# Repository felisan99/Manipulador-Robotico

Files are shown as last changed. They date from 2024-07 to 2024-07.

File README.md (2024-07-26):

# Manipulado Robótico

Este proyecto consiste en un brazo robótico a pequeña escala controlado mediante gestos de la mano. A continuación, brindo una descripción detallada del proyecto, sus objetivos, tecnología y componentes. Toda la informacion necesaria para replicar el proyecto esta en este repositorio.

## Objetivo del Proyecto

El objetivo de este proyecto es poner en práctica y mejorar habilidades en diseño 3D, electrónica y programación. La idea es crear un robot que pueda moverse en respuesta a gestos de la mano reconocidos utiliando la camara de la laptop.

### Componentes Principales

- **Placa de desarrollo ESP32**: Microcontrolador utilizado para controlar los servomotores y recibir por comunicacion serial la posicion de los servo motores.
- **Servomotores**: Motores utilizados para mover las diferentes partes del brazo robótico. Se utilizaron 3 modelos diferentes el MG996R, el MG90S y el SG90; todos de 180 grados.
- **Librería Mediapipe**: Utilizada para el reconocimiento de gestos de la mano. Esta librería cuenta con un modelo de ML ya entrenado que asigna coordenadas a los puntos de la mano y utilizando esto se crean gestos específicos para controlar cada servomotor de forma individual. https://mediapipe-studio.webapps.google.com/studio/demo/hand_landmarker
- **Piezas 3D**: Se diseñaron todas las piezas en 3D utilizando la plataforma online Onshape. Se puede ver el diseño de cada pieza individual y el ensamblado del robot en linea utilizando el link a continuacion. https://cad.onshape.com/documents/74374851f9fe1f9305b27667/w/19e4e45ac711f04db92687c4/e/1d70554c7b11f0e40a28d2fe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

### Funcionamiento

1. **Reconocimiento de Gestos**: Utilizando Mediapipe, el sistema captura la posición de la mano y asigna coordenadads a puntos clave (landmarks).
2. **Interpretación de Gestos**: En python se interpretan estas coordenadas para identificar gestos específicos y actualizar el angulo del servo en cuestion.
3. **Comunicación con ESP32**: El angulo actualizado se envían al ESP32 a través de comunicación serial.
4. **Control de Servomotores**: El ESP32 recibe los angulos y mueve los servomotores correspondientes.

## Aprendizajes y Descubrimientos

Este proyecto ha sido una excelente oportunidad para mejorar en programación, diseño 3D y electrónica. También ha resaltado la importancia de investigar y aprovechar las herramientas disponibles en internet.

## Próximos Pasos

El objetivo principal es controlar el robot mediante gestos de la mano, pero también estoy trabajando en permitir su control vía web server y con un joystick.

## Cómo repliacrlo ? 

Para poder replicar el proyecto sera necesario imprimir en 3D todas las piezas. En la carpeta de STLs estan todos los archivos. Tambien es necesario conseguir algunos tornillos ( x 10 no se que tamaño).

Ademas, sera necesario adquirir algunos componentes de electronica:
1. 2 x Servo motor 180 grados MG996R.
2. 2 x Servo motor 180 grados SG90.
3. 1 x Servo motor 180 grados MG90S.
4. Placa ESP32 o similar.
5. Capacitor electrolitico de 47microF
6. Muchos cables macho-hembra y macho-macho
7. Una placa de cobre perforada

En lo que respecta al codigo, es importante instalar todas las dependencias. Para la parte de Python, en el archivo SRC estan las librerias con las versiones. Para el correcto funcionamiento de la placa es necesario instalar la libreria de ESP32Servo dentro del IDE de Arduino antes de subir el codigo a la placa.

## Contribuciones

¡Las contribuciones son bienvenidas! Si tenes mejoras, sugerencias o encontras errores no dudes en compartirlas conmigo.

## Algunas imagenes del proyecto 😎
### Imagen del robot armado en Onshape


### Imagen del reconocimiento de landmarks


### El robot



## Video 📹
https://youtu.be/EpP-zhdE344?si=p3kppYE0x0bFDBg7

## Datos de contacto

LinkedIn: https://www.linkedin.com/in/felipe-santisteban-facal-1a4452261/

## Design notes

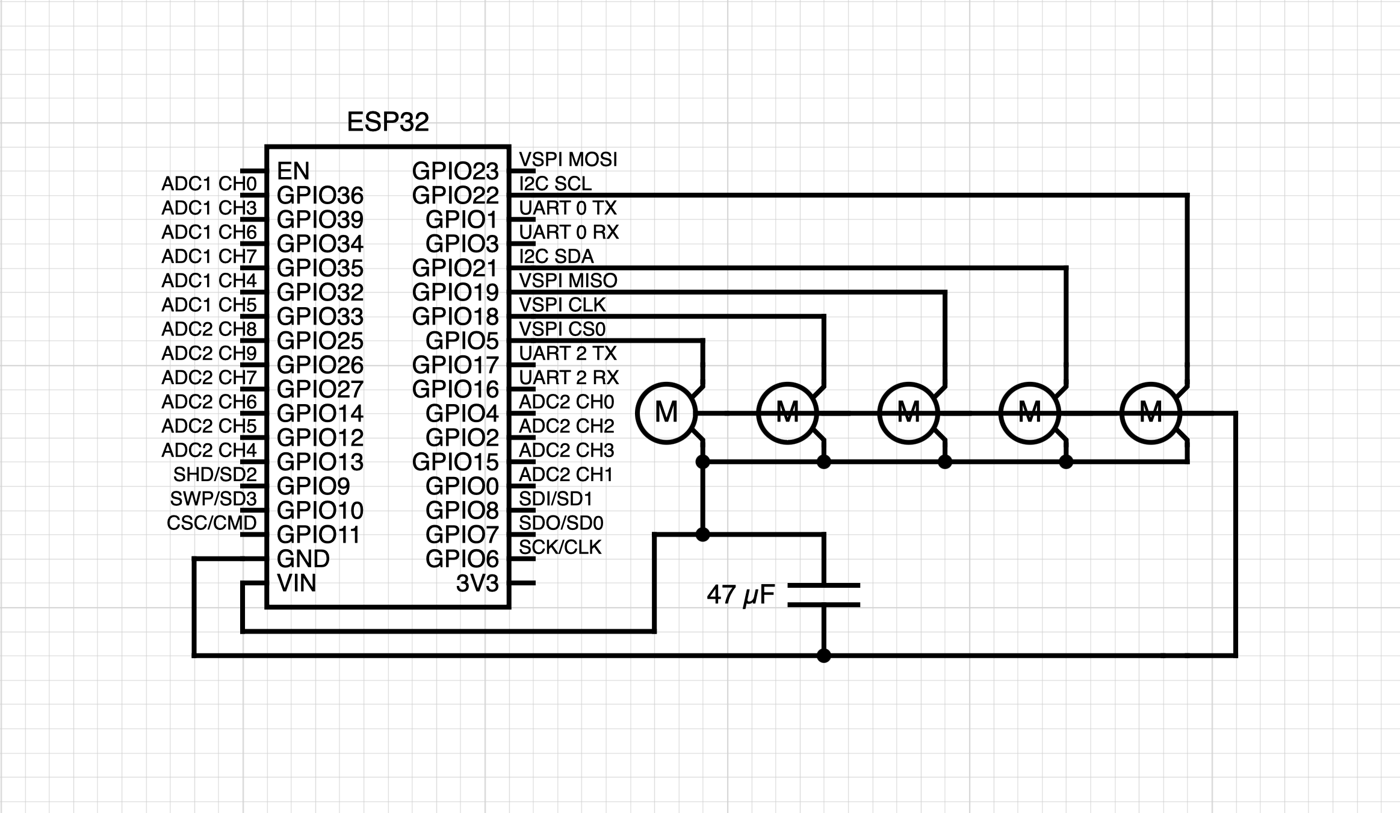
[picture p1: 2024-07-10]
Diagrama.png

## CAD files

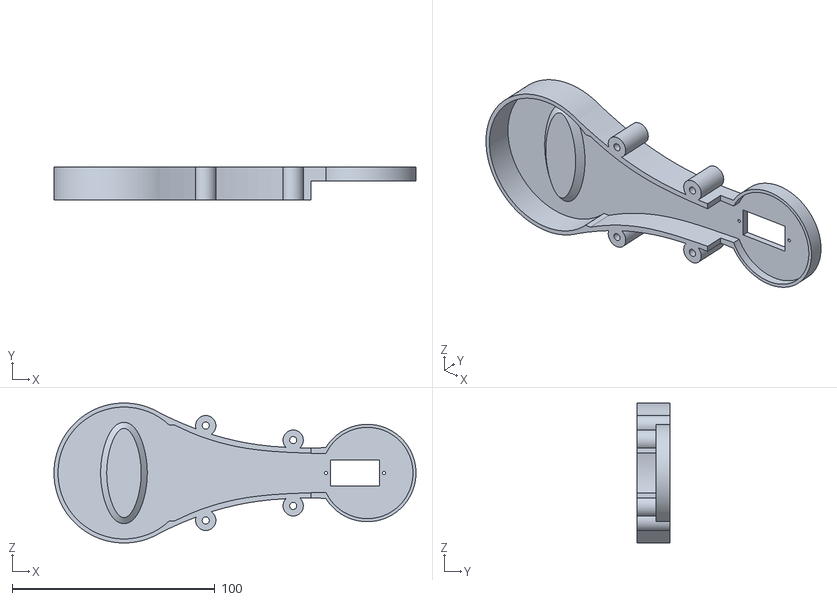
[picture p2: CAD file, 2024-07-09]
STL/Brazo_1/brazo_1 - Part 2.stl
178.5 x 16.5 x 69.0

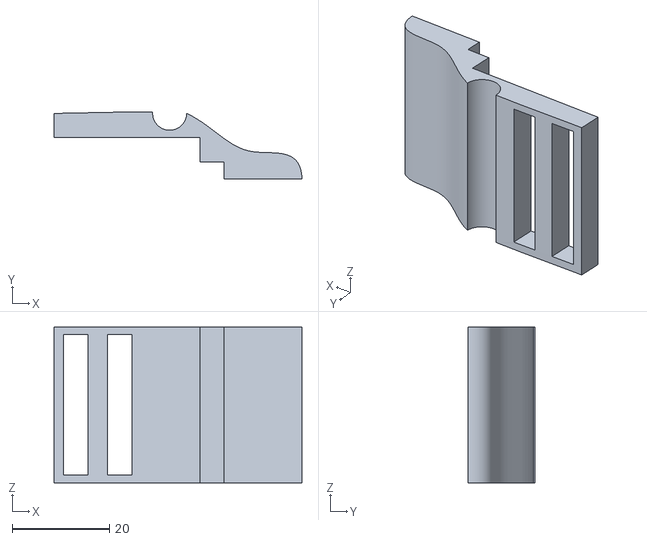
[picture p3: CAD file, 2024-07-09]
STL/Garra/agarre - Part 3.stl
51.0 x 13.8 x 32.0

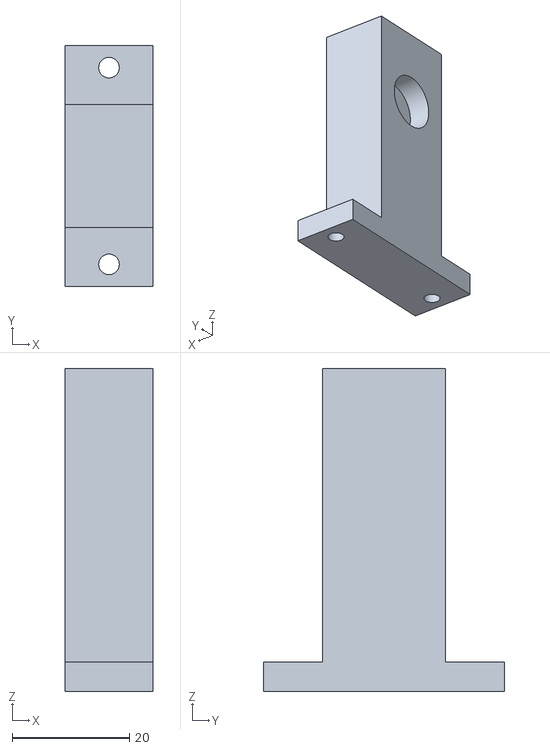
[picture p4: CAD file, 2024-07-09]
STL/Soporte_servo_1/soporte_brazo_1 - Part 2.stl
15.0 x 41.0 x 55.0

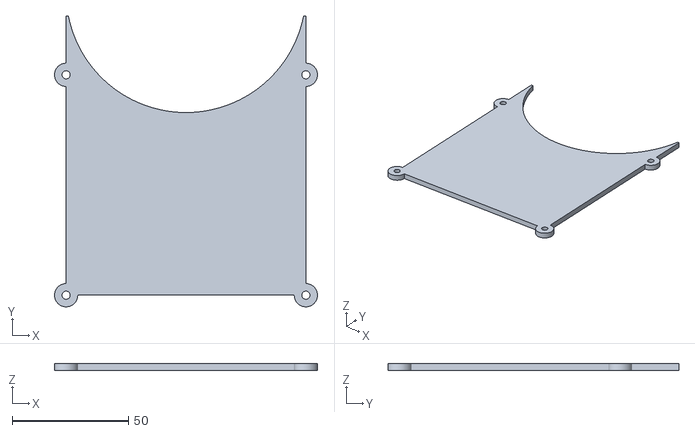
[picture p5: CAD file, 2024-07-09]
STL/Tapa_base.stl
113.0 x 124.9 x 3.00

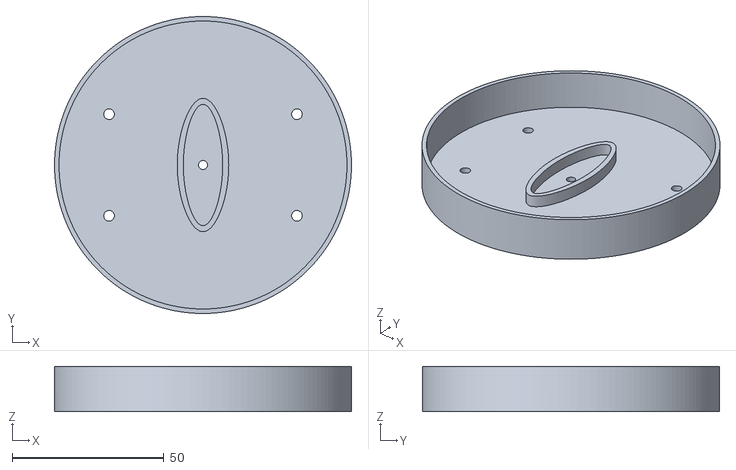
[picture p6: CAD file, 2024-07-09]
STL/Base_servo_1.stl
98.0 x 98.0 x 15.0

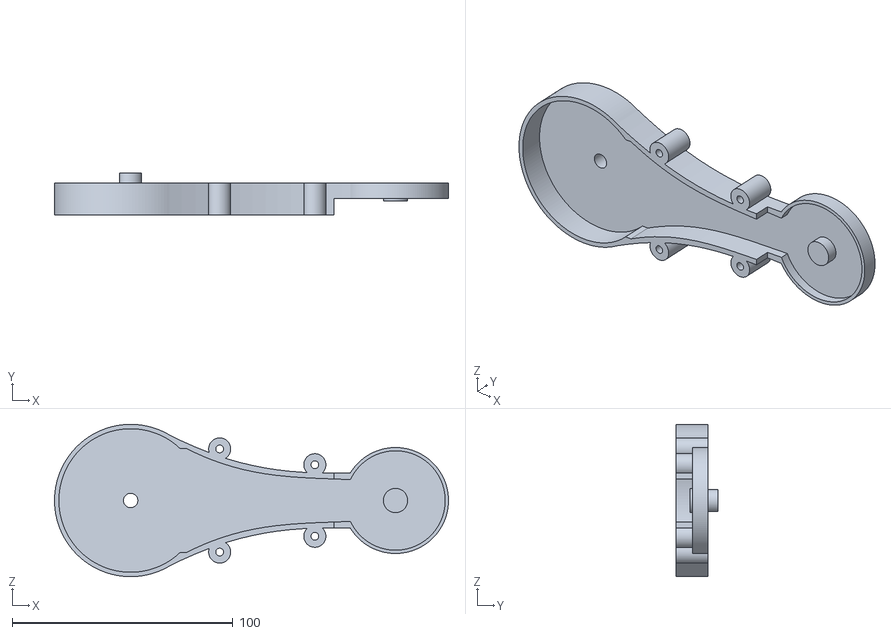
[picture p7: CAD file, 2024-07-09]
STL/Brazo_1/brazo_1 - Part 1.stl
178.5 x 19.2 x 69.0

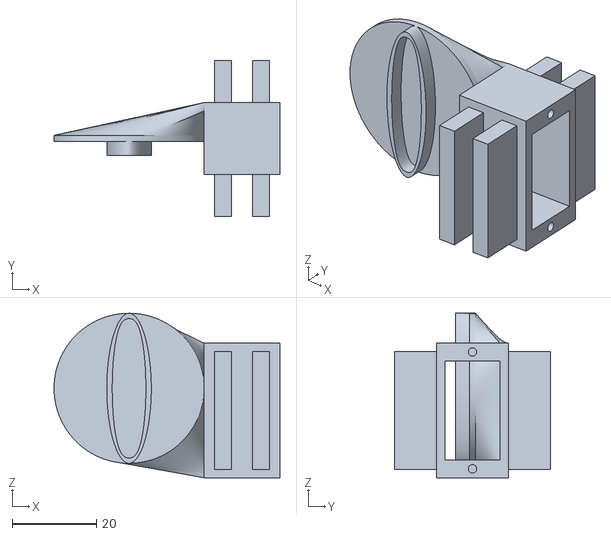
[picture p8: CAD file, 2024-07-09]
STL/Garra/agarre - Part 1.stl
53.6 x 37.0 x 39.0

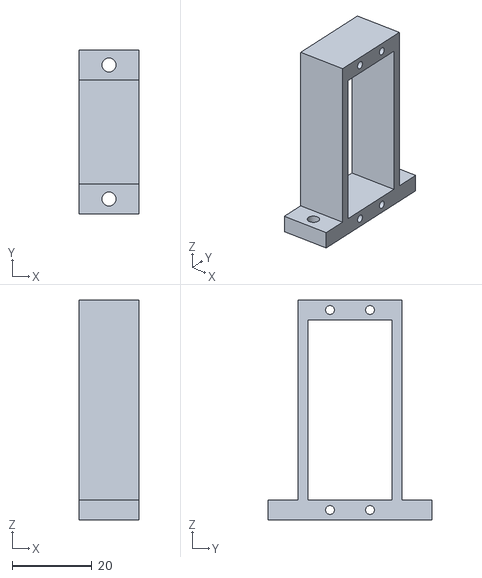
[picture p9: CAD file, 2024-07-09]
STL/Soporte_servo_1/soporte_brazo_1 - Part 1.stl
15.0 x 41.0 x 55.0

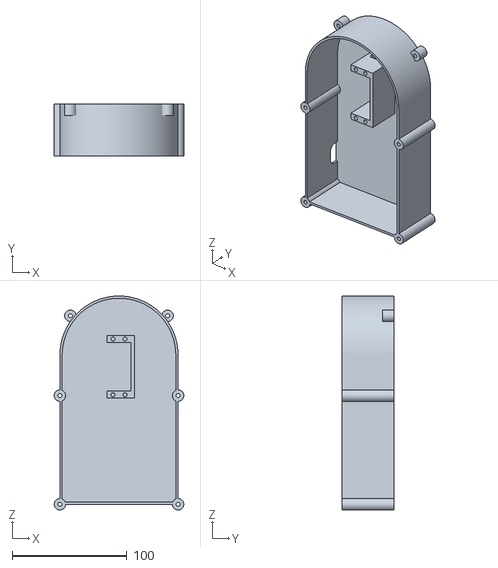
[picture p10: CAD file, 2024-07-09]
STL/Base.stl
113.0 x 45.0 x 186.5

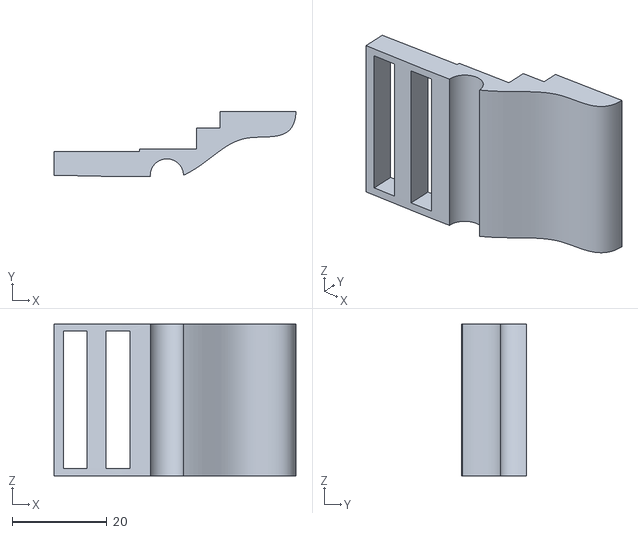
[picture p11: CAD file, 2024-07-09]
STL/Garra/agarre - Part 2.stl
51.0 x 13.8 x 32.0

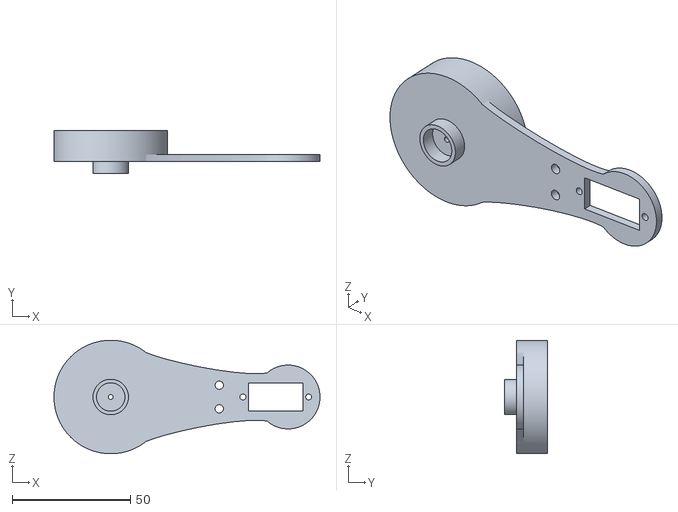
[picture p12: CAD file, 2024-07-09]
STL/Brazo_2.stl
112.5 x 18.0 x 48.0

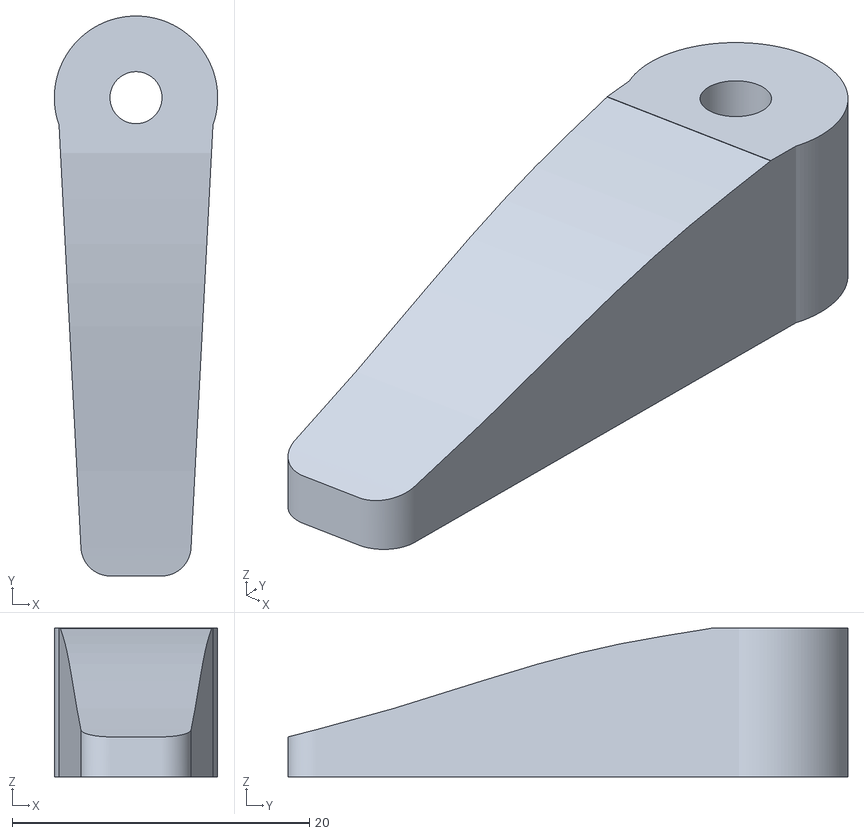
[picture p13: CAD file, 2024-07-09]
STL/Apoyo.stl
11.0 x 37.7 x 10.0

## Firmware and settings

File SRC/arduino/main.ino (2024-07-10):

#include <ESP32Servo.h>

const int pin_servo_base = 18;
const int pin_servo_brazo_1 = 19;
const int pin_servo_brazo_2 = 21;
const int pin_servo_brazo_3 = 22;
const int pin_servo_agarre = 5;

byte angulos[5];

Servo servo_base;
Servo servo_1;
Servo servo_2;
Servo servo_3;
Servo servo_agarre;

void setup() {
  Serial.begin(115200);

  servo_base.attach(pin_servo_base);
  servo_1.attach(pin_servo_brazo_1);
  servo_2.attach(pin_servo_brazo_2);
  servo_3.attach(pin_servo_brazo_3);
  servo_agarre.attach(pin_servo_agarre);
  
}

void loop() {
  if (Serial.available()){
    int datos_recibidos = Serial.readBytes(angulos, 5);
    if(datos_recibidos == 5){
      servo_base.write(angulos[0]);
      servo_1.write(angulos[1]);
      servo_2.write(angulos[2]);
      servo_3.write(angulos[3]);
      servo_agarre.write(angulos[4]);
    }
  }
}

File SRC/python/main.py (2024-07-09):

import serial
import cv2
import mediapipe as mp
import time as t

# Inicializacion del puerto serial 
ser = serial.Serial('/dev/cu.usbserial-0001', 115200)

# Inicializacion de variables
angulos_servo = [90, 90, 90, 90, 60] # base, brazo1, brazo2, brazo3, agarre
estado_garra = False  # Estado de la garra: False = abierta (60), True = cerrada (0)
reset_gesto_garra = False

# Inicializacion de los módulos de MediaPipe
mp_drawing = mp.solutions.drawing_utils
mp_drawing_styles = mp.solutions.drawing_styles
mp_manos = mp.solutions.hands

# Inicializacion de la camara
camara = cv2.VideoCapture(0)

# Funciones de utilidad
def limitar_valor(valor, minimo, maximo):
    return max(min(maximo, valor), minimo)

def estan_cerca(valor1, valor2, tolerancia):
    return abs(valor1 - valor2) < tolerancia

# Bucle principal
with mp_manos.Hands(model_complexity=0, min_detection_confidence=0.6, min_tracking_confidence=0.6) as manos:
    # Tiempos de retraso para que no se actualicen los ángulos de los servos muy rápido
    tiempo_garra = t.time()  # Tiempo para control de la garra

    while camara.isOpened():
        hay_mano, imagen = camara.read()

        imagen_rgb = cv2.cvtColor(imagen, cv2.COLOR_BGR2RGB)
        resultado = manos.process(imagen_rgb)

        if resultado.multi_hand_landmarks:
            for landmarks in resultado.multi_hand_landmarks:
                mp_drawing.draw_landmarks(
                    imagen, 
                    landmarks, 
                    mp_manos.HAND_CONNECTIONS, 
                    mp_drawing_styles.get_default_hand_landmarks_style(), 
                    mp_drawing_styles.get_default_hand_connections_style()
                )

                muneca_x = 1000 * landmarks.landmark[0].x
                dedo_gordo_x = 1000 * landmarks.landmark[4].x
                dedo_menique_x = 1000 * landmarks.landmark[20].x
                dedo_indice_x = 1000 * landmarks.landmark[8].x
                dedo_medio_x = 1000 * landmarks.landmark[12].x
                dedo_anular_x = 1000 * landmarks.landmark[16].x

                falange_indice_y = 1000 * landmarks.landmark[6].y
                falange_medio_y = 1000 * landmarks.landmark[10].y
                falange_anular_y = 1000 * landmarks.landmark[14].y
                falange_menique_y = 1000 * landmarks.landmark[18].y
                falange_gordo_y = 1000 * landmarks.landmark[2].y

                base_dedo_indice_y = 1000 * landmarks.landmark[5].y
                base_dedo_medio_y = 1000 * landmarks.landmark[9].y
                base_dedo_anular_y = 1000 * landmarks.landmark[13].y
                base_dedo_menique_y = 1000 * landmarks.landmark[17].y

                muneca_y = 1000 * landmarks.landmark[0].y
                dedo_indice_y = 1000 * landmarks.landmark[8].y
                dedo_menique_y = 1000 * landmarks.landmark[20].y
                dedo_medio_y = 1000 * landmarks.landmark[12].y
                dedo_anular_y = 1000 * landmarks.landmark[16].y
                dedo_gordo_y = 1000 * landmarks.landmark[4].y

                # Control del agarre 
                if estan_cerca(dedo_gordo_x, dedo_menique_x, 30) and estan_cerca(dedo_gordo_y, dedo_menique_y, 30) and not estan_cerca(dedo_gordo_y, dedo_indice_y, 100) and not estan_cerca(dedo_menique_y, dedo_anular_y, 100) and t.time() - tiempo_garra > 1 and dedo_medio_y < falange_medio_y and dedo_indice_y < falange_indice_y and dedo_anular_y < falange_anular_y:
                    tiempo_garra = t.time()
                    if(angulos_servo[4] == 60):
                        angulos_servo[4] = 0
                    else:
                        angulos_servo[4] = 60

                # Movimiento articulacion 1
                if dedo_indice_y > falange_indice_y and falange_medio_y > dedo_medio_y and falange_anular_y > dedo_anular_y and falange_menique_y > dedo_menique_y:
                        # Esta apuntando con un dedo para abajo
                        angulos_servo[1] = limitar_valor(angulos_servo[1] - 4, 0, 180)
                elif dedo_indice_y < falange_indice_y and dedo_medio_y > falange_medio_y and dedo_anular_y > falange_anular_y and dedo_menique_y > falange_menique_y:
                        # Esta apuntando con un dedo para arriba
                        angulos_servo[1] = limitar_valor(angulos_servo[1] + 4, 0, 180)
                
                # Movimiento articulacion 2
                if dedo_indice_y < muneca_y and dedo_indice_y < falange_indice_y and dedo_medio_y < muneca_y and dedo_medio_y < falange_medio_y and falange_anular_y < dedo_anular_y and falange_menique_y < dedo_menique_y:
                     # Esta apuntando con dos dedos para arriba
                    angulos_servo[2] = limitar_valor(angulos_servo[2] + 4, 0, 180)
                elif dedo_indice_y > muneca_y and dedo_indice_y > falange_indice_y and dedo_medio_y > falange_medio_y and dedo_anular_y < falange_anular_y and dedo_menique_y < falange_menique_y:
                    angulos_servo[2] = limitar_valor(angulos_servo[2] - 4, 0, 180)
                
                # Movimiento articulacion 3
                if estan_cerca(dedo_gordo_x, dedo_indice_x, 50) and estan_cerca(dedo_indice_x, dedo_medio_x, 50) and estan_cerca(dedo_medio_x, dedo_anular_x, 50) and estan_cerca(dedo_anular_x, dedo_menique_x, 50) and estan_cerca(dedo_gordo_y, dedo_medio_y, 50):
                    if dedo_menique_y < falange_menique_y and dedo_gordo_y < falange_gordo_y:
                        angulos_servo[3] = limitar_valor(angulos_servo[3] + 4, 0, 180)
                    else:
                        angulos_servo[3] = limitar_valor(angulos_servo[3] - 4, 0, 180)
                    
                # Movimiento de la base
                if abs(dedo_anular_x - 50 - muneca_x) > 100 and dedo_anular_y < falange_anular_y and dedo_menique_y < falange_menique_y and dedo_medio_y < falange_medio_y and dedo_indice_y < falange_indice_y:
                    if dedo_anular_x > muneca_x:
                        angulos_servo[0] = limitar_valor(angulos_servo[0] - 4, 0, 180)
                    else:
                        angulos_servo[0] = limitar_valor(angulos_servo[0] + 4, 0, 180)
        

        ser.write(bytearray(angulos_servo))
        print(angulos_servo)

        cv2.putText(imagen, str(angulos_servo), (10, 30), cv2.FONT_HERSHEY_SIMPLEX, 1, (150, 100, 0), 2, cv2.LINE_AA)
        cv2.imshow('MediaPipe Hands', imagen)
        

        if cv2.waitKey(5) & 0xFF == 27:
            break

camara.release()
cv2.destroyAllWindows()
